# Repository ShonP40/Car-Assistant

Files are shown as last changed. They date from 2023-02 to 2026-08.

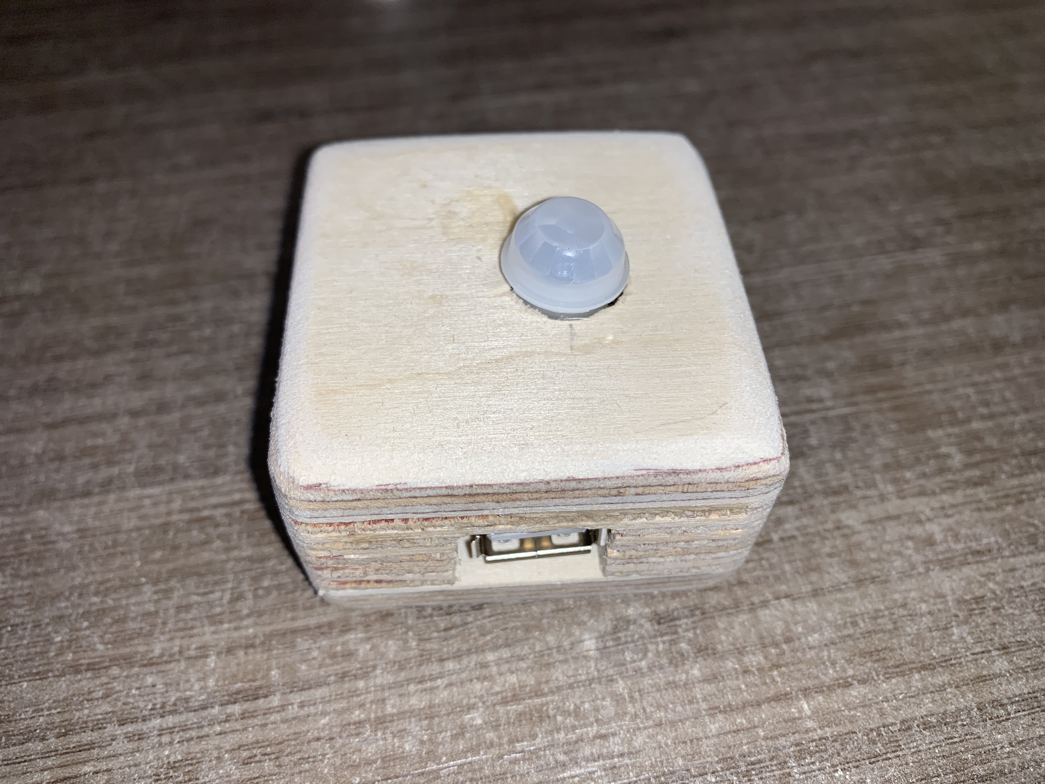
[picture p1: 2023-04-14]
PCB/Photos/Enclosure/10 - Sensors (PIR - Assembled).jpeg

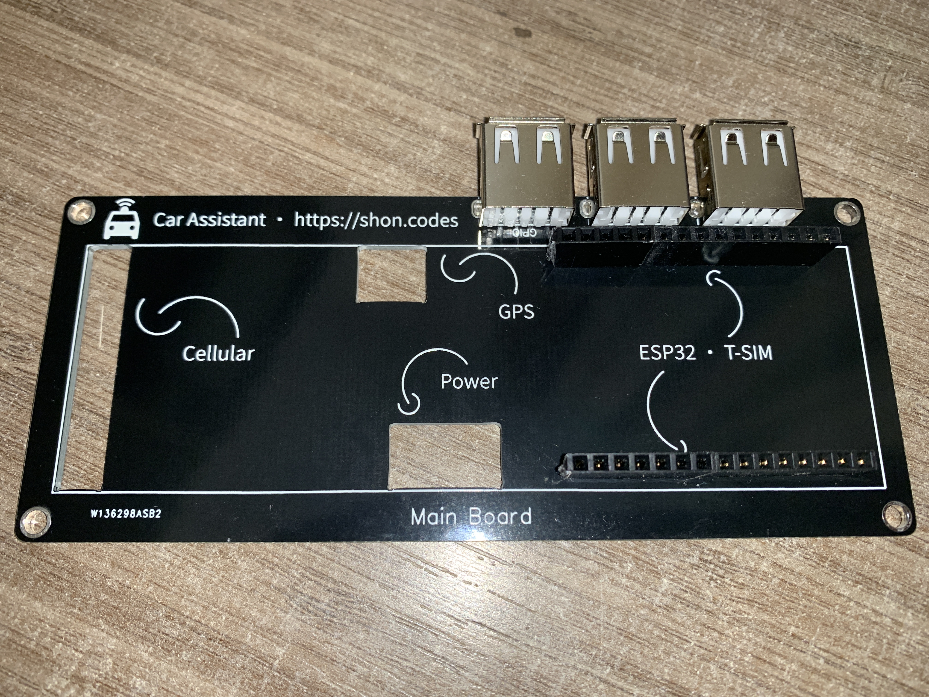
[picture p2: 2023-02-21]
PCB/Photos/PCB/03 - Top Layer Soldered (Main).jpeg

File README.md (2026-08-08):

<p align="center">
    
</p>

<h1 align="center">Car Assistant</h1>
<h3 align="center">Keep track of your car remotely through Home Assistant</h3>

## Sponsor


This project has been sponsored by [PCBWay](https://www.pcbway.com/)!

You can order this project from PCBWay at a $5 discount by using my [referal link](https://www.pcbway.com/setinvite.aspx?inviteid=590728)

## Features
- OTA updates (Over a WireGuard VPN connection, cellular NAT IP or locally through the WiFi hotspot)
- Cellular connectivity
- Automatically update the ESP's clock
- WireGuard VPN connection
- SD card support through a web server
- Broadcast a Bluetooth iBeacon (to detect which phones are in the car, by using the `iBeacon Scanner` sensor in the Home Assistant app)
- Report battery status (percentage, voltage, USB charging, solar charging & discharging)
- Report network details (public IP, Cellular NAT IP, WireGuard IP, Cellular network type, Cellular signal strength and Cellular network type)
- Report location status (latitude, longitude, speed, altitude, visible satellites, horizontal dilution of precision, accuracy and course)
- Report the uptime of the ESP in seconds
- Report your car's temperature, humidity and air pressure using a BME280 sensor
- Report the light level inside your car using a TSL2561 sensor
- Detect motion inside your car's cabin using a PIR sensor or a mmWave radar
- Report the CPU temperature and frequency
- Report the free RAM & PSRAM amounts
- Reboot the ESP32 & Modem remotely
- Broadcast a WiFi hotspot with internet access

## Software Requirements
- ESPHome 2025.12.7 (Newer versions will not work at the moment)
- Home Assistant server
- WireGuard VPN server or an MQTT broker
- USB <-> Serial driver ([`macOS`](https://github.com/Xinyuan-LilyGO/CH9102_Mac_Driver) | [`Linux`](https://github.com/gorgiaxx/CH34x-Driver-Linux) | [`Windows`](https://github.com/Xinyuan-LilyGO/CH9102_Driver))

## Hardware Requirements
- LilyGO® TTGO T-SIM7600E-L1C ESP32 (Other ESP32 TTGO models could also work)
- A Nano SIM Card with an active internet plan
- Cellular antenna
- GPS antenna
- 18650B battery
- BME280 sensor (optional)
- TSL2561 sensor (optional)
- PIR sensor (like the AM312) thats pulled low by default (optional)
- LD2410S mmWave radar (optional)
- Micro SD Card formatted as FAT32 (optional)

## Connectors
- I2C1 - GPIO 21 (SDA) & 22 (SCL)
- I2C2 - GPIO 21 (SDA) & 22 (SCL)
- GPIO - GPIO 19 & 23

## Boards preview
Assembled PCB

## Enclosures preview
Assembled Enclosures

More pictures can be found [here](./PCB/Photos)

## Installation

Follow these steps to get your Car Assistant device up and running with ESPHome.

### ESPHome Integration Setup

1. Install the ESPHome app in Home Assistant if not already installed:
   - Go to `Settings` → `Apps` → `Install app`
   - Search for `ESPHome`
   - Click `Install`
2. Start the ESPHome app and verify that it's running
3. Access the ESPHome dashboard through Home Assistant

### Setup Device

1. In the ESPHome dashboard, click `+ New Device`
2. Name your device (e.g., "Car Assistant")
3. Select `ESP32` as your device type
4. Copy the default configuration to your new device from [here](./car-assistant.yaml)
5. Modify the configuration in the user config section
6. Click `Save` and then `Install`

### Device Flashing

Initial flashing must be done via serial connection.

[ESPHome Web](https://web.esphome.io) is recommended for the simplest experience.

#### Required Hardware
- USB-C to USB-A cable

#### Flashing Process
1. Connect the T-SIM7600E-L1C to a computer using a USB-C cable
2. Visit [ESPHome Web](https://web.esphome.io)
3. Connect to your device and flash the firmware you compiled earlier
4. After a successful flash, the device will restart and be ready for OTA updates

### Device Tracker
Create a new [template device tracker](https://www.home-assistant.io/integrations/template/#device-tracker) in Home Assistant and link the `Latitude`, `Longitude` and `Location Accuracy` Car Assistant entities to be able to display your car on the map

### Recover from GPS failures
Import the restart on GPS failure blueprint into Home Assistant to automatically restart your Car Assistant's modem & ESP32 if GPS fails and does not recover



## Credits
- [Xinyuan-LilyGO](https://github.com/Xinyuan-LilyGO/T-SIM7600X) - Basic T-SIM7600X implementation
- [oarcher](https://github.com/esphome/esphome/pull/6721#issuecomment-3362380809) - ESPHome SIM7600 implementation & Blueprint device tracker
- [n-serrette](https://github.com/n-serrette/esphome_sd_card) - ESPHome SDCard implementation

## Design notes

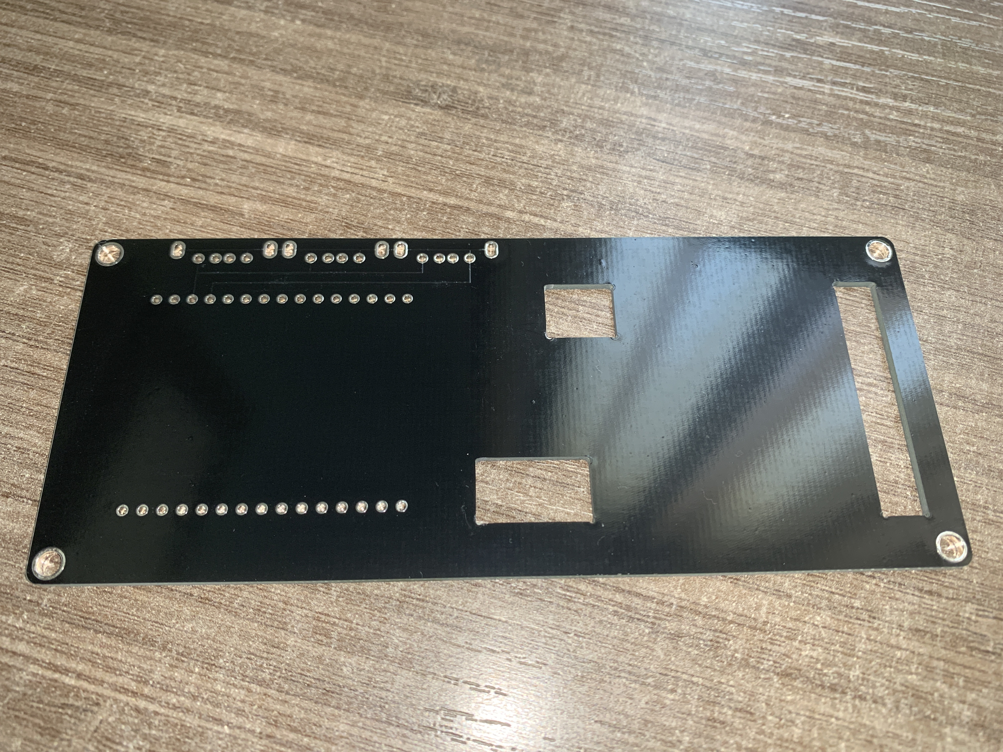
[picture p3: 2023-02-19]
PCB/Photos/PCB/02 - Bottom Layer (Main).jpeg

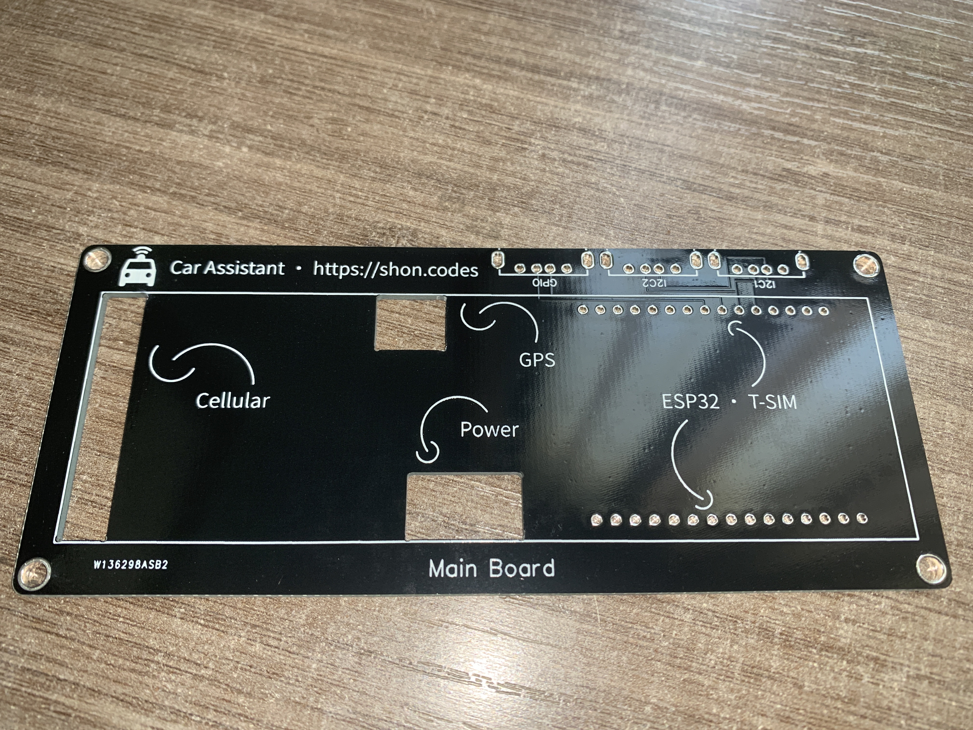
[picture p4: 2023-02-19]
PCB/Photos/PCB/01 - Top Layer (Main).jpeg

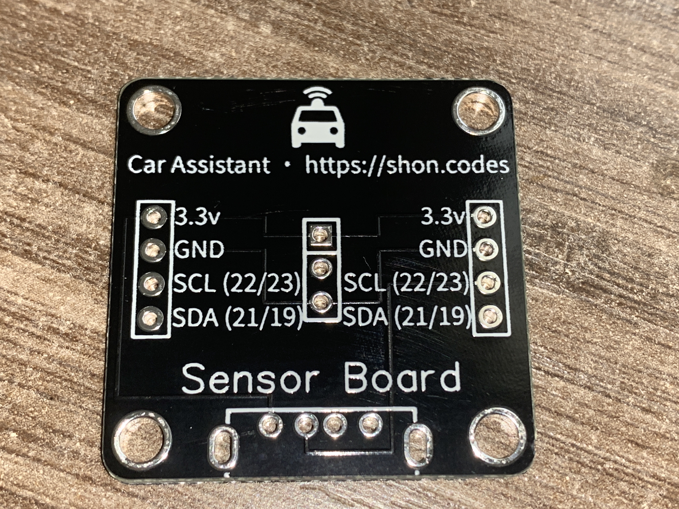
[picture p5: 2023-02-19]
PCB/Photos/PCB/06 - Top Layer (Sensors).jpeg

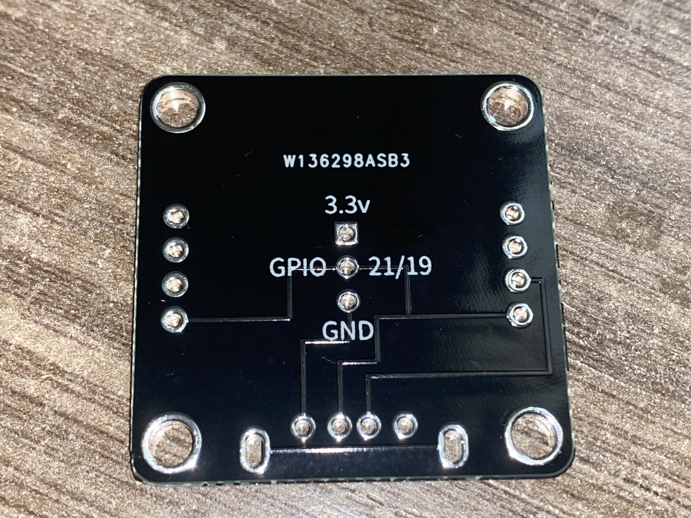
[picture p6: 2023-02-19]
PCB/Photos/PCB/07 - Bottom Layer (Sensors).jpeg

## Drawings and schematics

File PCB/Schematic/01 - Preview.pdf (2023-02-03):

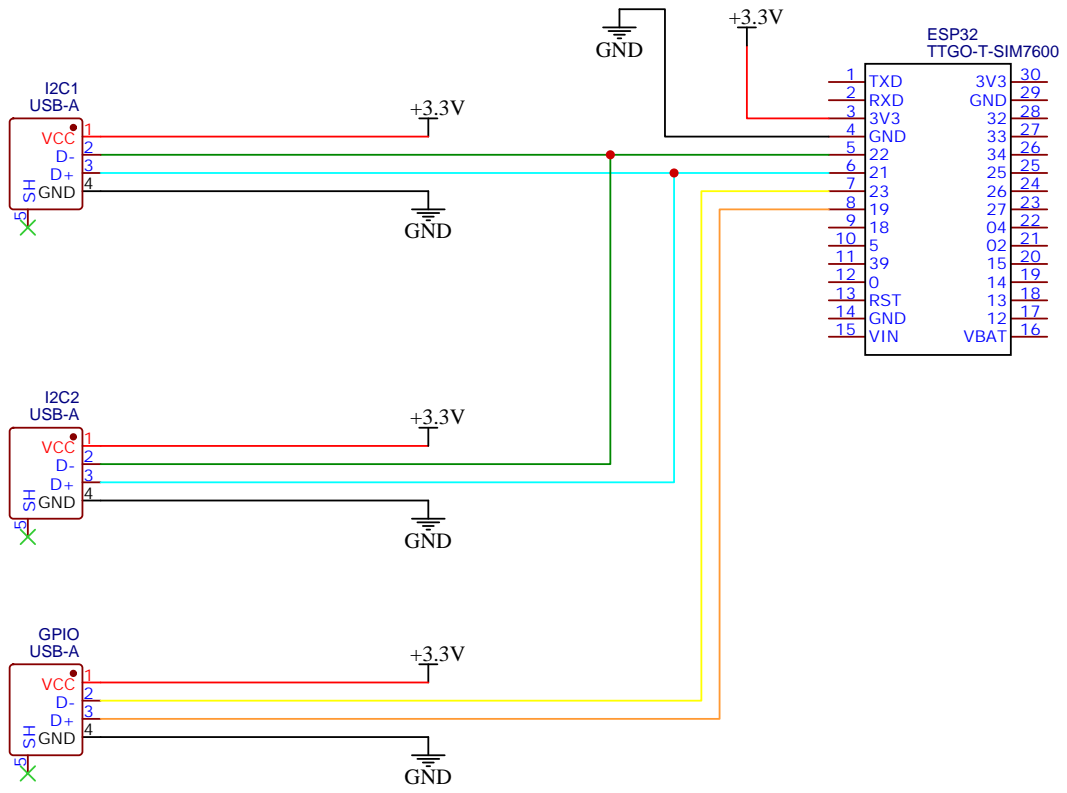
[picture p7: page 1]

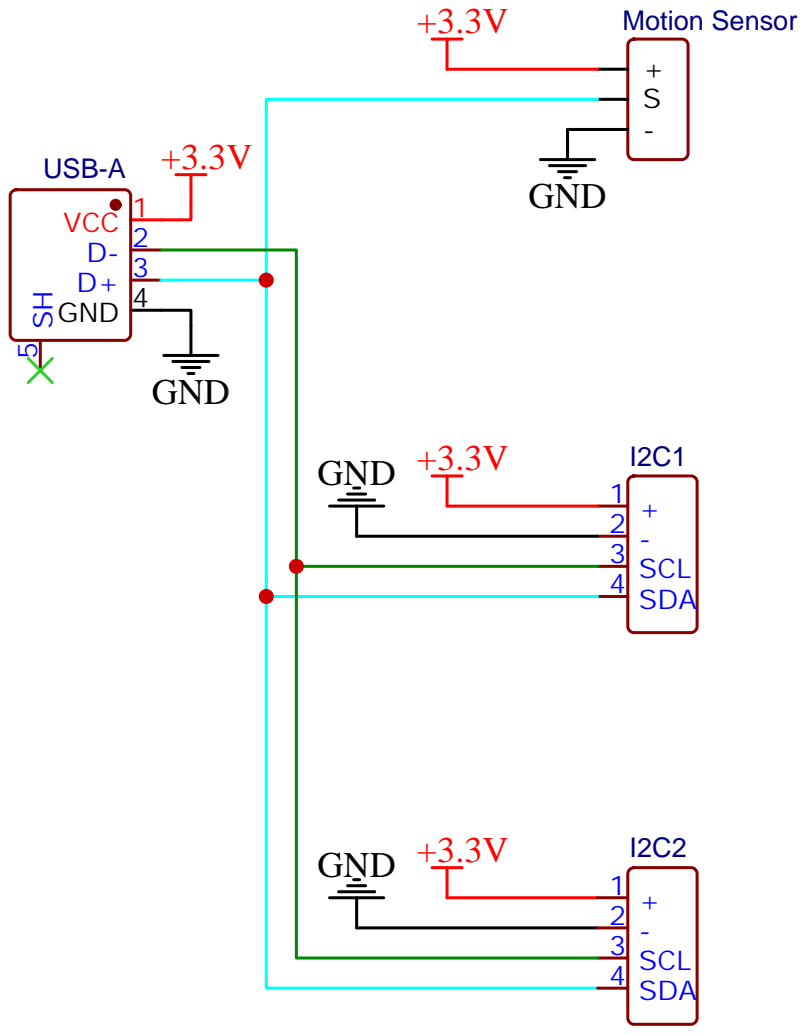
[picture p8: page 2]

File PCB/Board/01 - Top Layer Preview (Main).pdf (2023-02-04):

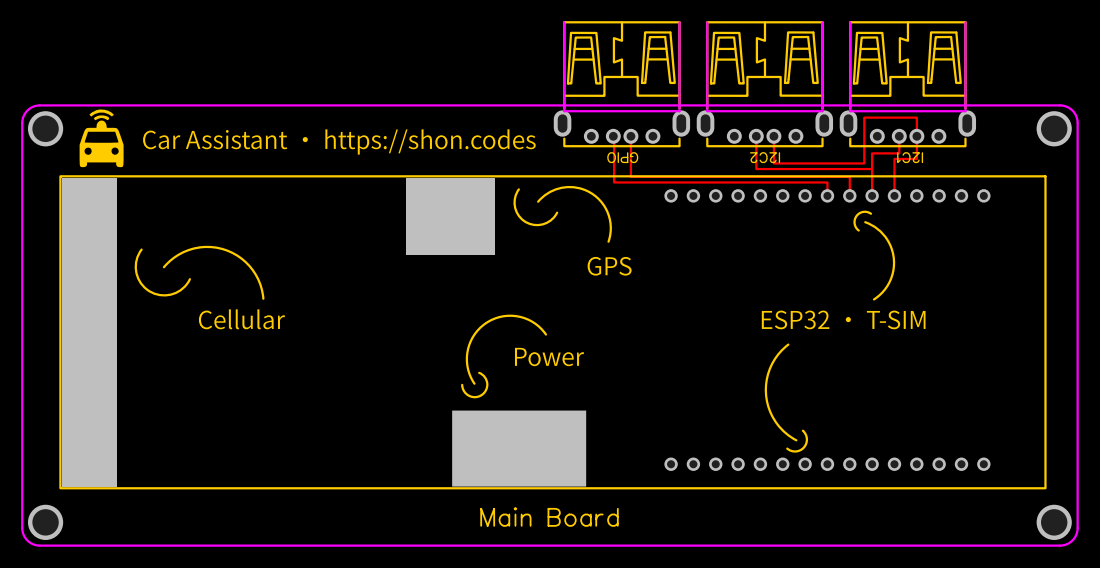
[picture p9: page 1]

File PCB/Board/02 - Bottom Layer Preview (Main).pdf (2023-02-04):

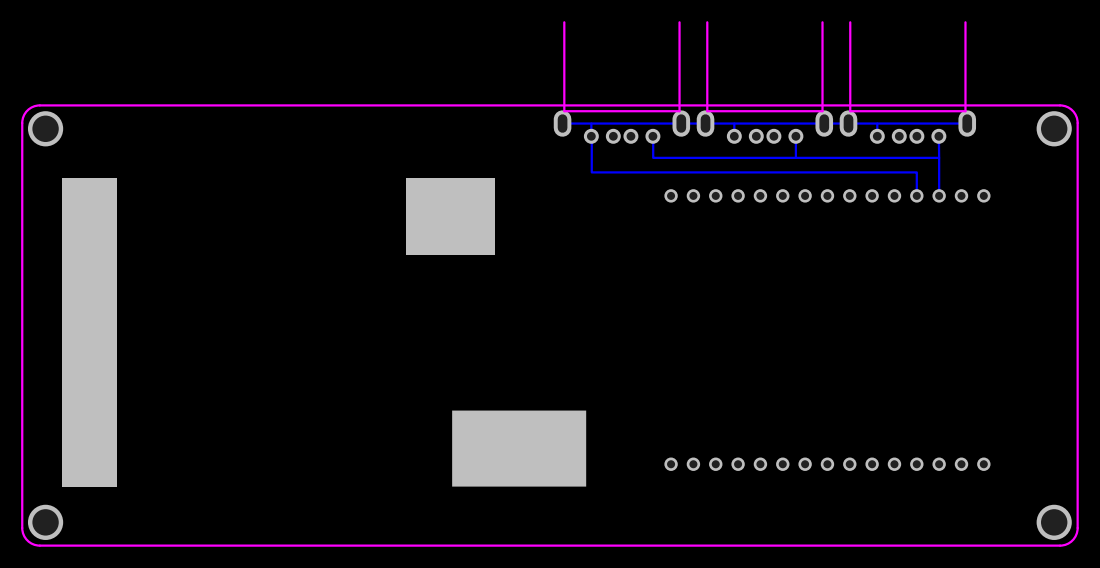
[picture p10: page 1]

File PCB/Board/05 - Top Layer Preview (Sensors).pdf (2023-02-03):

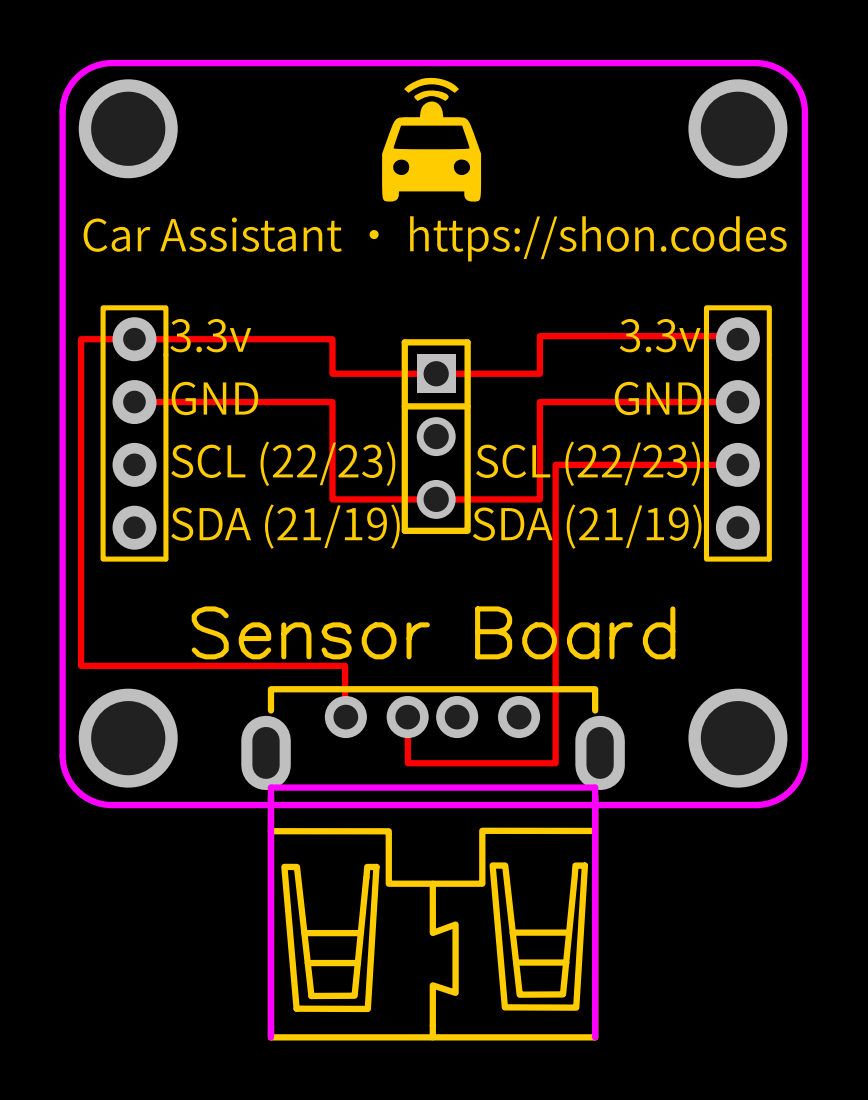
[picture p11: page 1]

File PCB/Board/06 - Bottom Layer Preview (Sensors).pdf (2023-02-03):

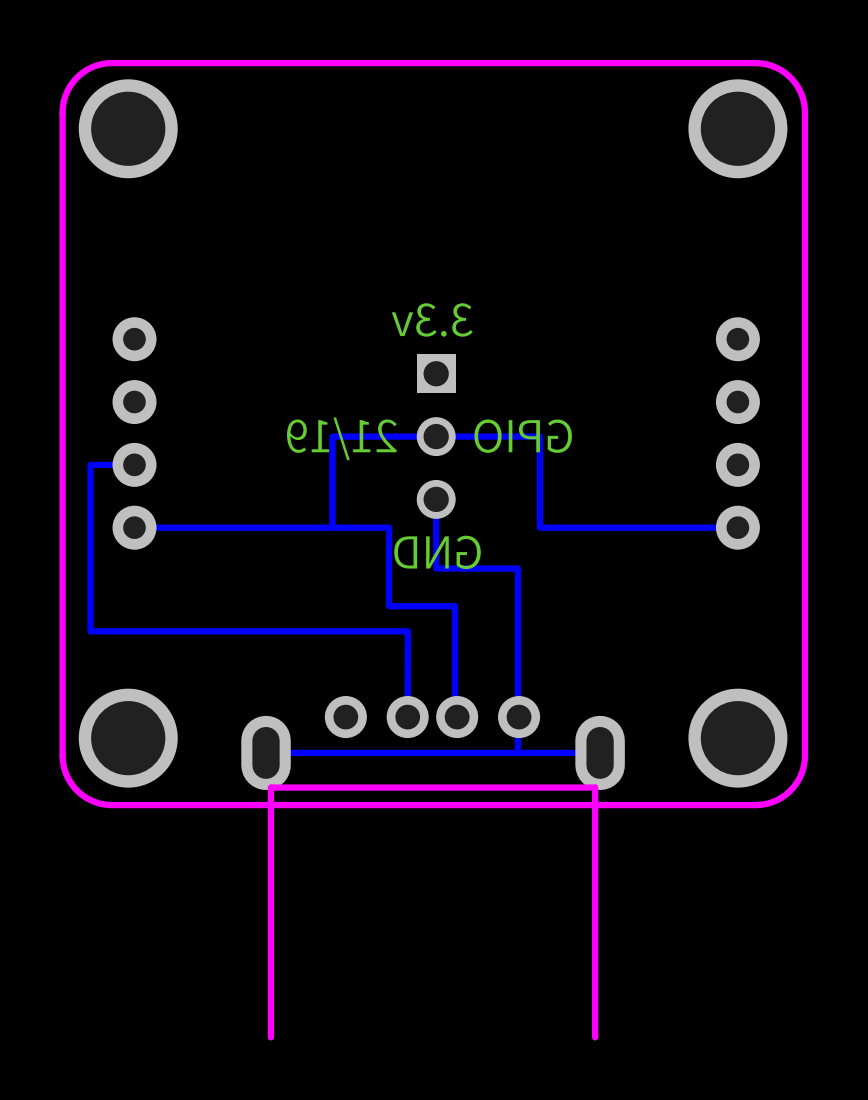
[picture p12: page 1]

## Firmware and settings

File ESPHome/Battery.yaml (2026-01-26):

####################################################################################################
#####                                    Car Assistant                                         #####
#####                  Repository: https://github.com/ShonP40/Car-Assistant                    #####
####################################################################################################
##### Purpose: Battery & charging sensors                                                      #####
####################################################################################################
##### NOTE:                                                                                    #####
##### - Make changes ONLY if absolutely necessary and you have the required knowledge.         #####
##### - For normal system use, modifications to this file are NOT required.                    #####
####################################################################################################

sensor:
  - platform: adc
    pin: ${battery_pin}
    name: "${friendly_name} Battery Voltage"
    id: ${id}_battery_voltage
    attenuation: 11db
    filters:
      - lambda: return (x / 2700.0) * 4200.0;
    unit_of_measurement: "V"
    accuracy_decimals: 2
  - platform: template
    name: "${friendly_name} Battery Percentage"
    icon: mdi:battery
    unit_of_measurement: "%"
    accuracy_decimals: 0
    lambda: |-
      const float battery_min = 2.2;
      const float battery_max = 4.2;
      float voltage = id(${id}_battery_voltage).state;
      if (voltage < battery_min) {
        return 0;
      } else {
        float percentage = ((voltage - battery_min) / (battery_max - battery_min)) * 100;
        return (percentage > 100) ? 100 : percentage;
      }
  - platform: adc
    pin: ${battery_solar_indicator_pin}
    name: "${friendly_name} Solar Indicator"
    id: ${id}_solar_indicator
    attenuation: 11db
    unit_of_measurement: "V"
    accuracy_decimals: 2

text_sensor:
  - platform: template
    name: "${friendly_name} Charging Status"
    icon: mdi:battery-charging
    lambda: |-
      if (id(${id}_solar_indicator).state > 0.5) {
        return {"Solar Charging"};
      } else if (id(${id}_battery_voltage).state < 1) {
        return {"USB/GPIO Charging"};
      } else {
        return {"Discharging"};
      }

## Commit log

2022-07-28 Layout change, print public IP & fix serial msgs
2022-07-28 Calculate battery percentage
2023-02-03 Added the pinout for when using the GPIO USB
    [Drill_PTH_Through.DRL, Drill_PTH_Through_Via.DRL, Gerber_BoardOutlineLayer.GKO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]
2023-02-04 Reduced the screwhole size on the main board
    [Drill_PTH_Through.DRL, Drill_PTH_Through_Via.DRL, Gerber_BoardOutlineLayer.GKO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]
2023-02-06 Sponsored by PCBWay!
2023-02-19 Added a few photos of the PCBs
2023-02-19 Battery charging status (USB & Solar supported)
2023-02-19 Turn off the blue ESP LED when running on battery
2023-02-24 Load config into variables & add a restart button
2023-02-25 Lower case this
2023-02-25 Report the CPU temperature to MQTT
2023-02-26 Replace `config.h` with per board build config
2023-02-26 Dynamic CPU frequency scaling for power saving
2023-02-26 Move the update & restart buttons to the header
2023-03-07 Added support for the ESP32's Hall sensor
2023-03-07 Ability to switch to 160MHz when on battery
2023-03-11 Example HA automation to update the device tracker
2023-03-30 Added a photo with all 4 boards assembled
2023-04-14 [Home Assistant] Configure PIR as a binary sensor
2023-04-14 Added pictures of the enclosures
2023-04-15 [HA] Add a device class to the PIR sensor
2023-04-15 Fixed AP disconnections & wrong battery percentage
2023-04-15 Fix reporting battery status when charging via USB
2023-04-23 Update the min battery voltage
2023-04-23 Prevent reporting negative battery percentages
2023-04-24 [HA] Added a unit of measurement for hall effect
2023-04-24 Turn GPS off when running on battery if in LP mode
2023-04-24 Disable WiFi hotspot when on battery if in LP mode
2023-04-25 This board seems to cut off at 2.7V
2023-09-25 Ability to reboot the modem & ESP32 over MQTT
2025-05-20 Fixed the state being spammed
    And `home` state being reported twice (once lower case and once with an
    uppercase `H`)
2025-10-03 Moved `time` to the WireGuard config
    As its not required anywhere else
2025-10-03 Added the modem status pin into the `modem` config
2025-10-03 Added icons to all the sensors
2025-10-03 Fixed battery voltage reporting & debug
    [Battery.yaml]
2025-10-03 Fix charging indicator
2025-10-03 Fix the charging indicator v2
    [Battery.yaml]
2025-10-04 Added a Blueprint based device tracker
    Thanks [oarcher](https://gist.github.com/oarcher) for making it!
2025-10-04 Added a modem restart button
2025-10-05 Allow OTA updates through the ESPHome dashboard
    By setting the use_address field to WireGuard's IP
2025-10-05 Added GPS time as a fallback
    To maintain a WireGuard connection even if NTP servers are down
2025-10-05 Display the GPS speed on the device tracker
2025-10-06 Added a GNSS status sensor
2025-10-06 Added debounce to the GNSS status sensor
2025-10-06 Update this sensor every minute
2025-10-06 Revert "Update this sensor every minute"
    This reverts commit d83bdf1aa388a304950b4e979e128f1cb22e387f.
2025-10-06 Revert "Added a GNSS status sensor"
2025-10-20 Added Home Assistant BLE Proxy support
    Useful if you want to track phone presence in the car or have BLE devices in the car that you want to pass to Home Assistant
2025-10-20 Added a photo of the mmWave radar sensor
2026-01-26 Change minimum battery voltage threshold to 2.2V
2026-04-11 Added support for pre-shared WireGuard keys
2026-05-29 Switch licenses
2026-08-08 Template device tracker instead of an automation
